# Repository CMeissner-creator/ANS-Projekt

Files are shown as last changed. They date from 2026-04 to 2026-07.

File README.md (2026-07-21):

# ANS-Projekt

Das ANS-Projekt hat zum Ziel einen 5,5 MHz Colpitts Oszilator zu entwerfen

- Kundenwünsche / Ursprüngliche Zielsetzung
- KiCad Projekte der Entwicklung
- Messwerte des Aufbau

Die Website wird automatisch aus dem Ordner `docs/` generiert.

# Kunden Anforderungen
- 5,5 MHz Mittenfrequenz (Zwischenfrequenz Fernseher)
- Eingang 0 V
- linear ± 0,5 V ≙ ± 0,5 MHz
- Bandbreite von 5 bis 6 MHz
- nicht lineare Verzerrung sehr klein
- Robuste Platine für anschaulichen Unterricht
- große Bauteile
- Spannungsteiler integriert
- Ein- und Ausgang BNC
- Ausgangswiderstand 50 Ω
- Frequenzdrift durch Gleichspannung korrigiert
- Kennlinienermittlung mit Gleichspannung
- Kurzschluss sicher

## Quellen für den Colpitts Oszillator
- [Elektroniktutor FM Modulation](https://www.elektroniktutor.de/signalkunde/fm.html)
- [Elektroniktutor Colpitts Oszillator](https://www.elektroniktutor.de/signalkunde/colpitts.html)

### Coilpitts Oszillator in Emitterschaltung für 125 kHz

Als erstes haben wir den Colpitts Oszillator für für 125 kHz von der Elektroniktutor
Seite in KiCad und danach auf einer Platine aufgebaut.

[Schaltplan als PDF](/docs/assets/Colpitts_Oszillator.pdf)

Danach haben wir versucht diesen Oszilator auf 5,5 Mhz umzubauen:

[Schaltplan als PDF](/docs/assets/Colpitts_Oszillator_5.5MHz.pdf)

In der NGSpice / KiCad Simulation funktioniert der Oszilator so, aber in der Realität nicht.
Das Problem ist, dass ein Colpitts Oszilator in der Emitterschaltung bei so hohen Frequenzen nicht funktioniert.
Die Millerkapazität, des Transistor, macht die Emitterschaltung unmöglich im MHz Bereich.

#### Colpitts Oszillator in Basisschaltung für 5,5 MHz

So sind wir schließlich bei einem Colpitts Oszillator in Basisschaltung gelandet.

[Schaltplan als PDF](/docs/assets/FM-ELK.pdf)

Dieser funktioniert so im Steckbrettaufbau.

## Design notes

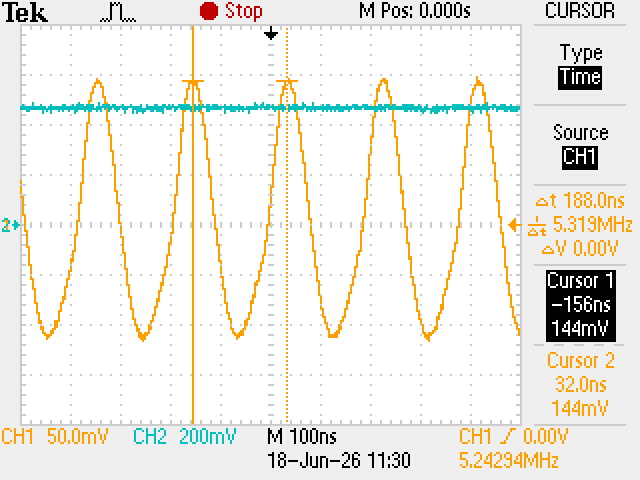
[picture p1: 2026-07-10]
Messungen/Oszillator_Bilder/TEK0002.JPG

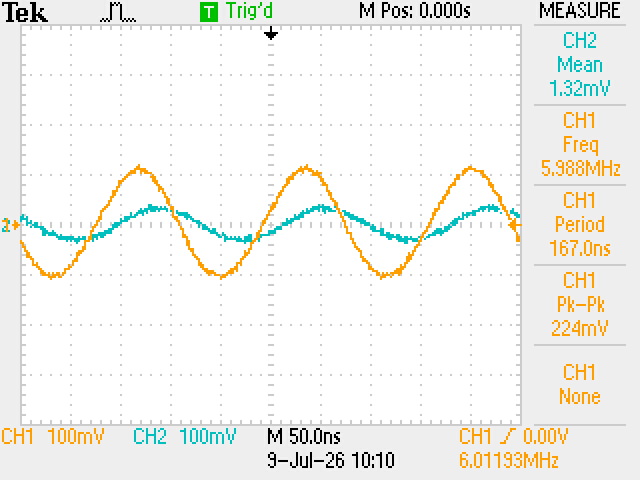
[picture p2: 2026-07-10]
Messungen/Messung 09.07.2026/TEK0008.JPG

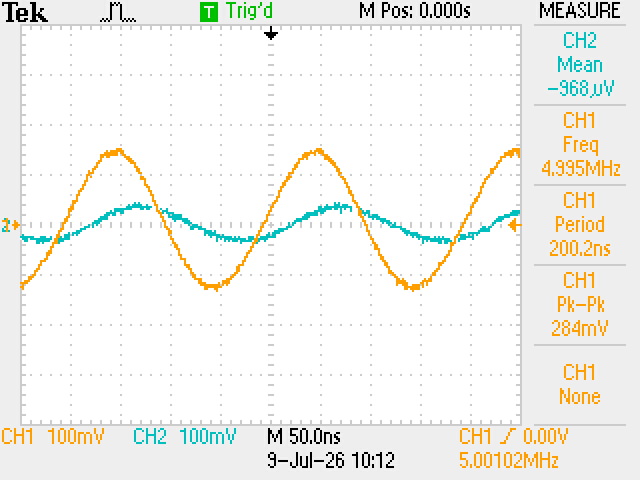
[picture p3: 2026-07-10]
Messungen/Messung 09.07.2026/TEK0010.JPG

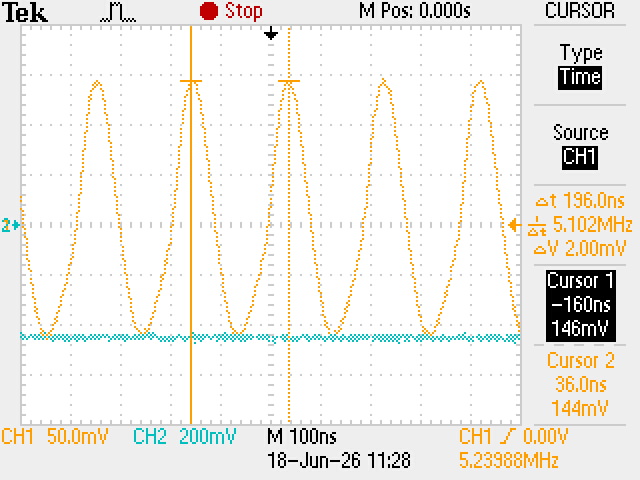
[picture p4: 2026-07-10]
Messungen/Oszillator_Bilder/TEK0001.JPG

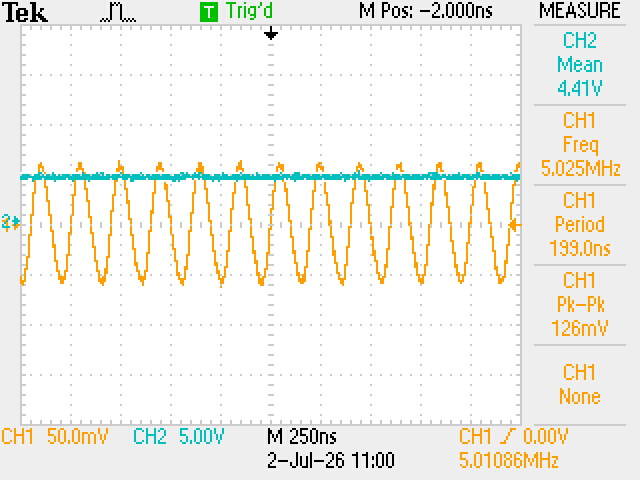
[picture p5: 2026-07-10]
Messungen/Oszillator_Bilder/TEK0007.JPG

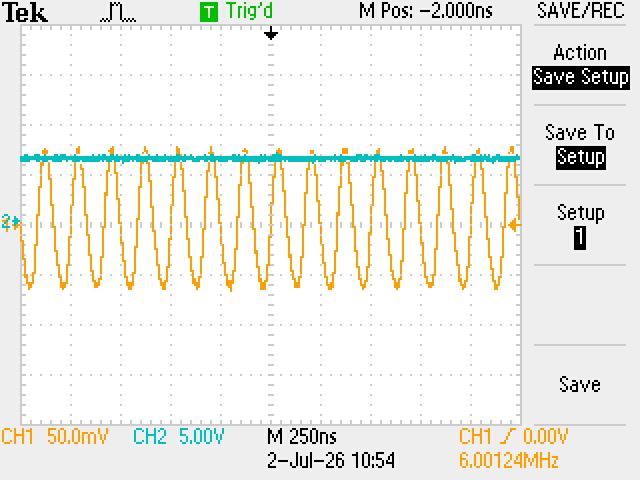
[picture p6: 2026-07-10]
Messungen/Oszillator_Bilder/TEK0004.JPG

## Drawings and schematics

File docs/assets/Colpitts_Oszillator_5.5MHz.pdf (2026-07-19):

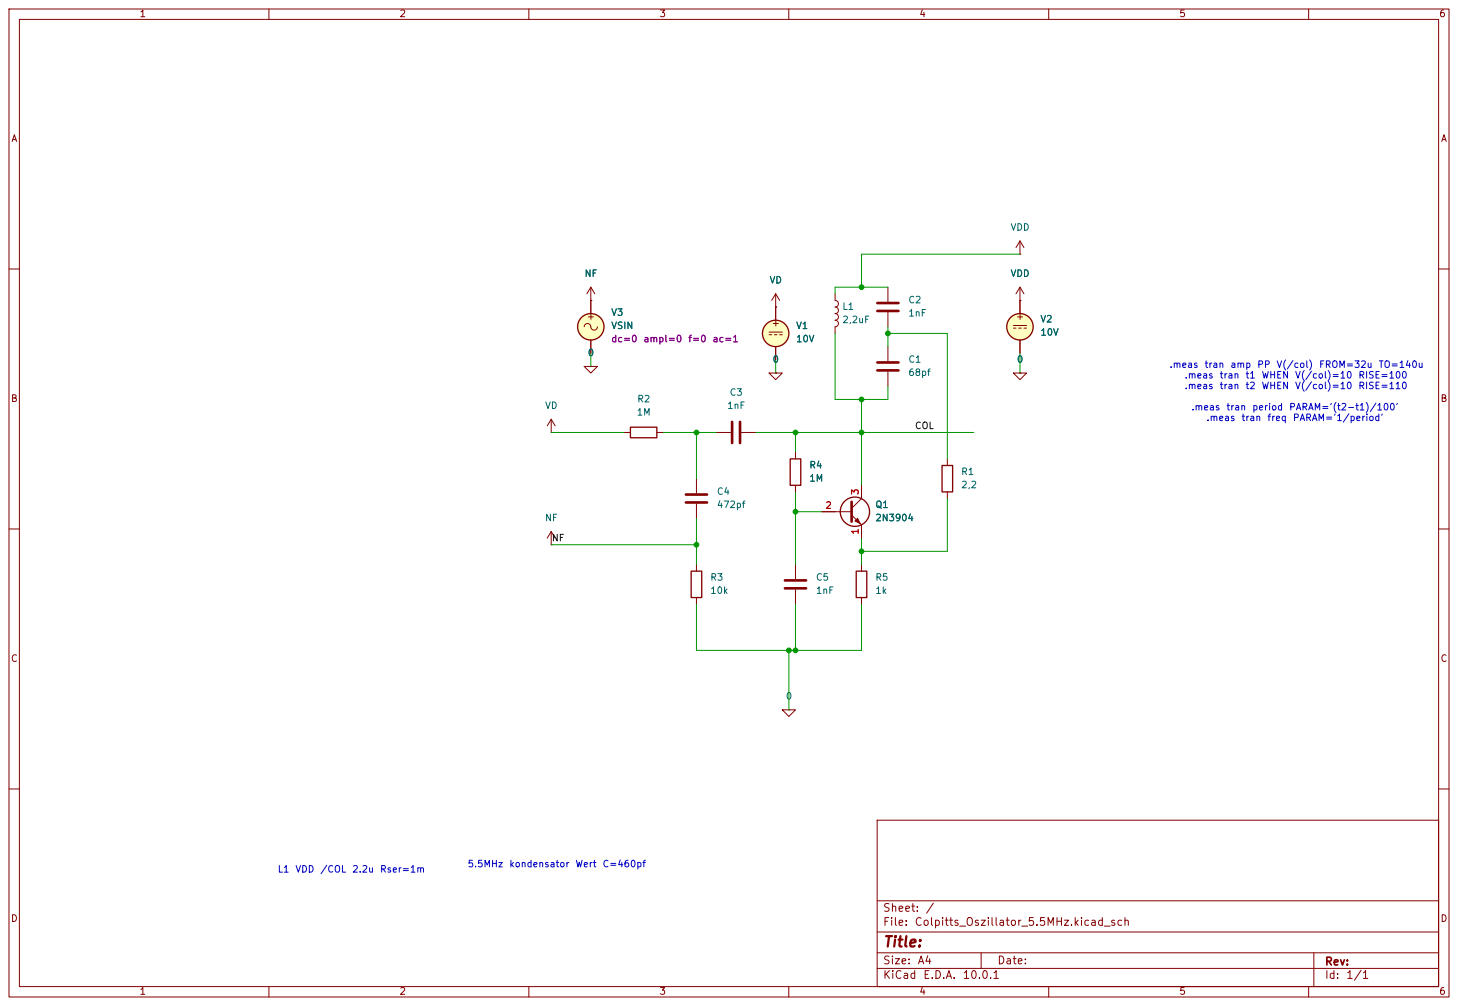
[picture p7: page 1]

.meas tran amp PP V(/col) FROM=32u TO=140u
.meas tran t1 WHEN V(/col)=10 RISE=100
.meas tran t2 WHEN V(/col)=10 RISE=110

.meas tran period PARAM='(t2-t1)/100'

.meas tran freq PARAM='1/period' 5.5MHz kondensator Wert C=460pf L1 VDD /COL 2.2u Rser=1m

Size: A4 | Rev:
KiCad E.D.A. 10.0.1 | Id: 1/1

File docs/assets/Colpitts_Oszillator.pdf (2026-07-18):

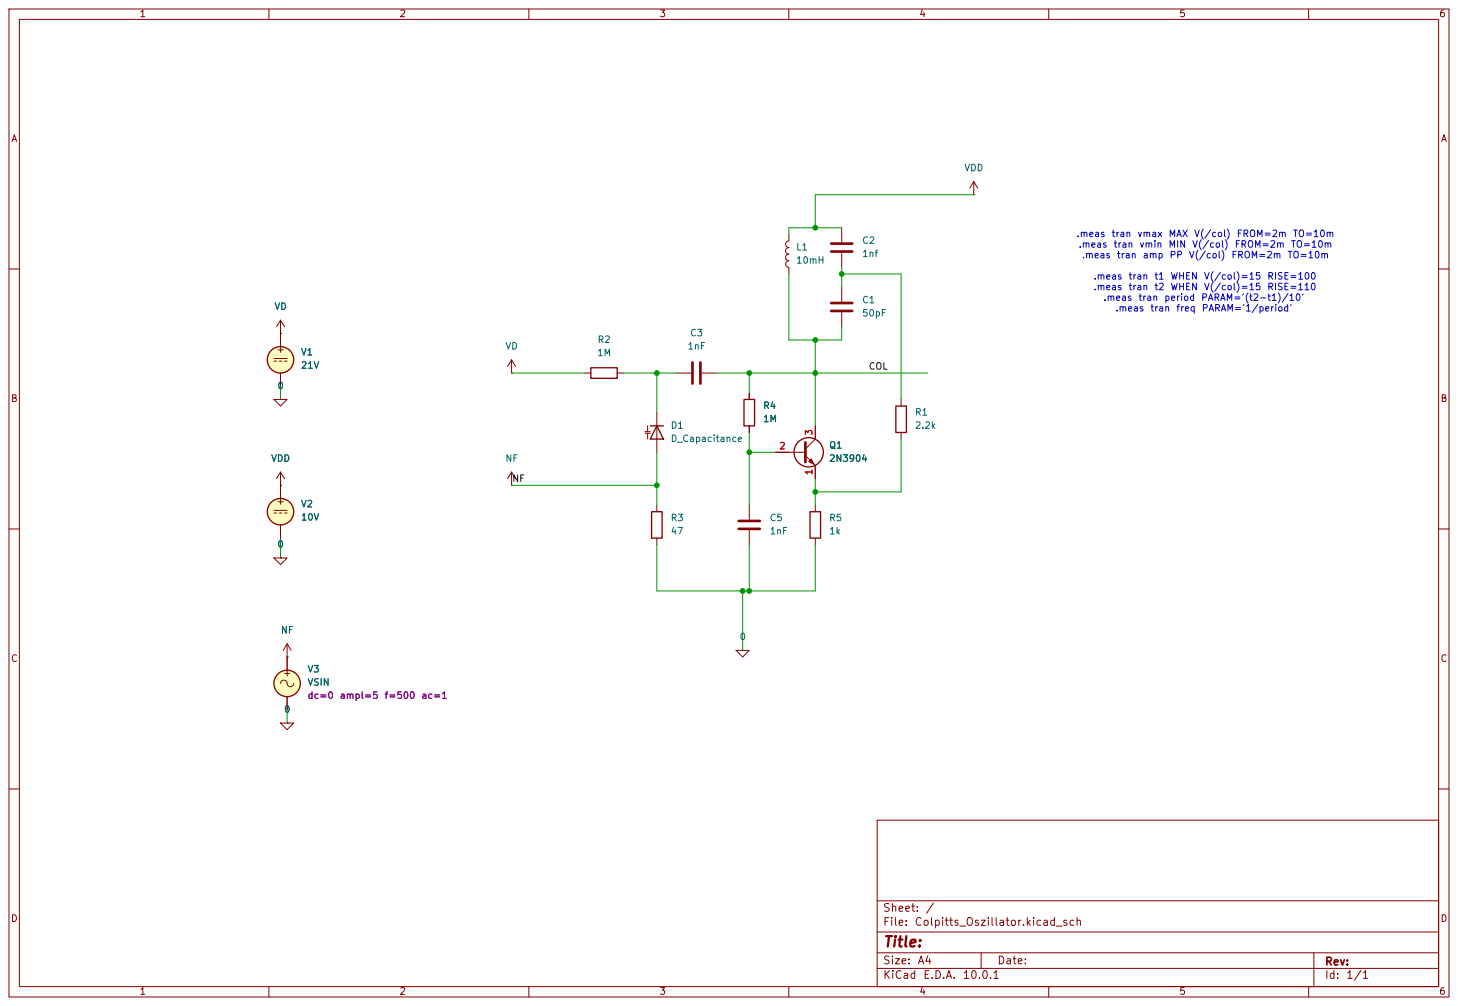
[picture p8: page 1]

.meas tran vmax MAX V(/col) FROM=2m TO=10m
.meas tran vmin MIN V(/col) FROM=2m TO=10m
.meas tran amp PP V(/col) FROM=2m TO=10m

.meas tran t1 WHEN V(/col)=15 RISE=100
.meas tran t2 WHEN V(/col)=15 RISE=110
.meas tran period PARAM='(t2-t1)/10'

.meas tran freq PARAM='1/period' Q1

Size: A4 | Rev:
KiCad E.D.A. 10.0.1 | Id: 1/1

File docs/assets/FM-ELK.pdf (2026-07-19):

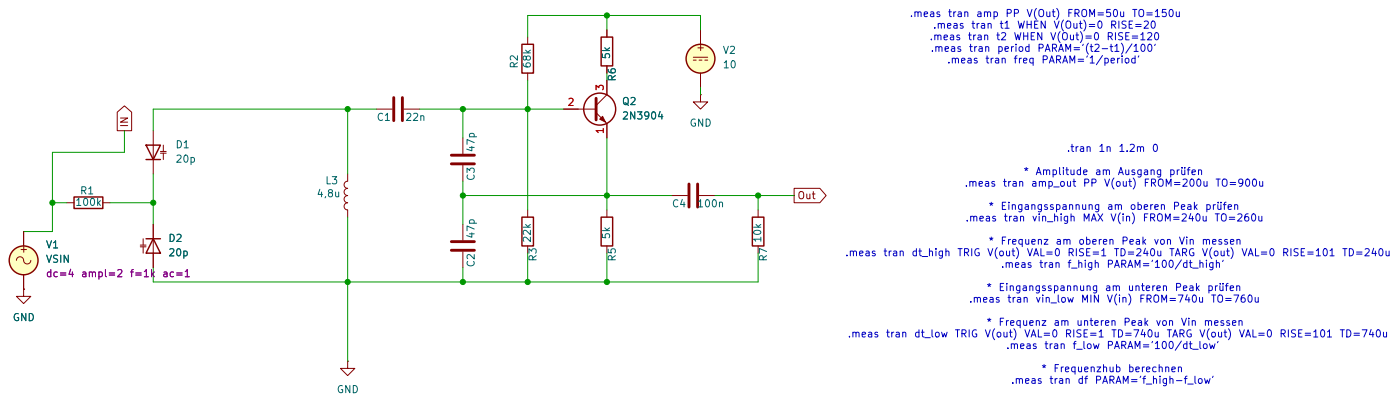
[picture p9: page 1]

.meas tran amp PP V(Out) FROM=50u TO=150u
.meas tran t1 WHEN V(Out)=0 RISE=20
.meas tran t2 WHEN V(Out)=0 RISE=120
.meas tran period PARAM='(t2-t1)/100'
.meas tran freq PARAM='1/period'

University of applied sience R268k

* Amplitude am Ausgang prüfen

.meas tran amp_out PP V(out) FROM=200u TO=900u

* Eingangsspannung am oberen Peak prüfen
.meas tran vin_high MAX V(in) FROM=240u TO=260u

* Frequenz am oberen Peak von Vin messen

.meas tran dt_high TRIG V(out) VAL=0 RISE=1 TD=240u TARG V(out) VAL=0 RISE=101 TD=240u

.meas tran f_high PARAM='100/dt_high' * Eingangsspannung am unteren Peak prüfen

.meas tran vin_low MIN V(in) FROM=740u TO=760u

* Frequenz am unteren Peak von Vin messen

.meas tran dt_low TRIG V(out) VAL=0 RISE=1 TD=740u TARG V(out) VAL=0 RISE=101 TD=740u

.meas tran f_low PARAM='100/dt_low' * Frequenzhub berechnen

Title: Name of circuit / Creator

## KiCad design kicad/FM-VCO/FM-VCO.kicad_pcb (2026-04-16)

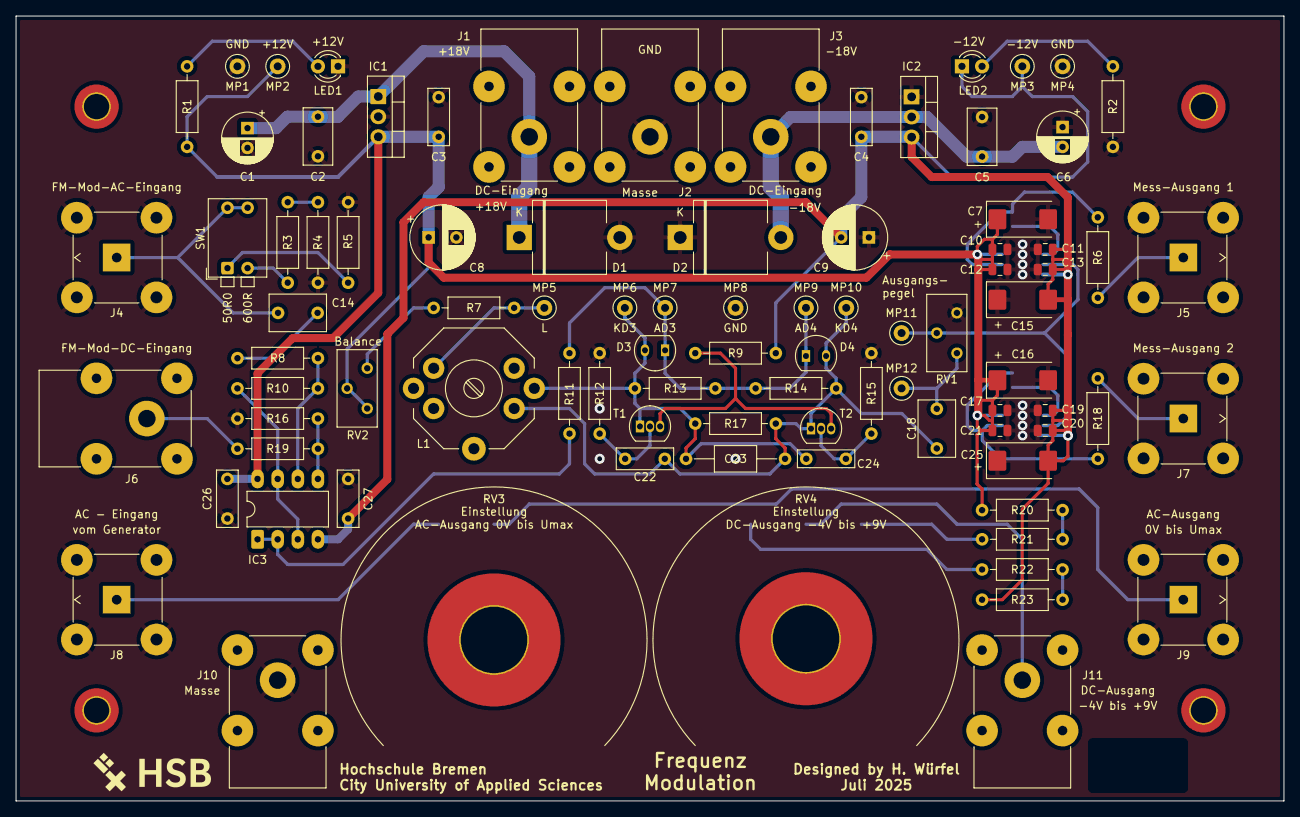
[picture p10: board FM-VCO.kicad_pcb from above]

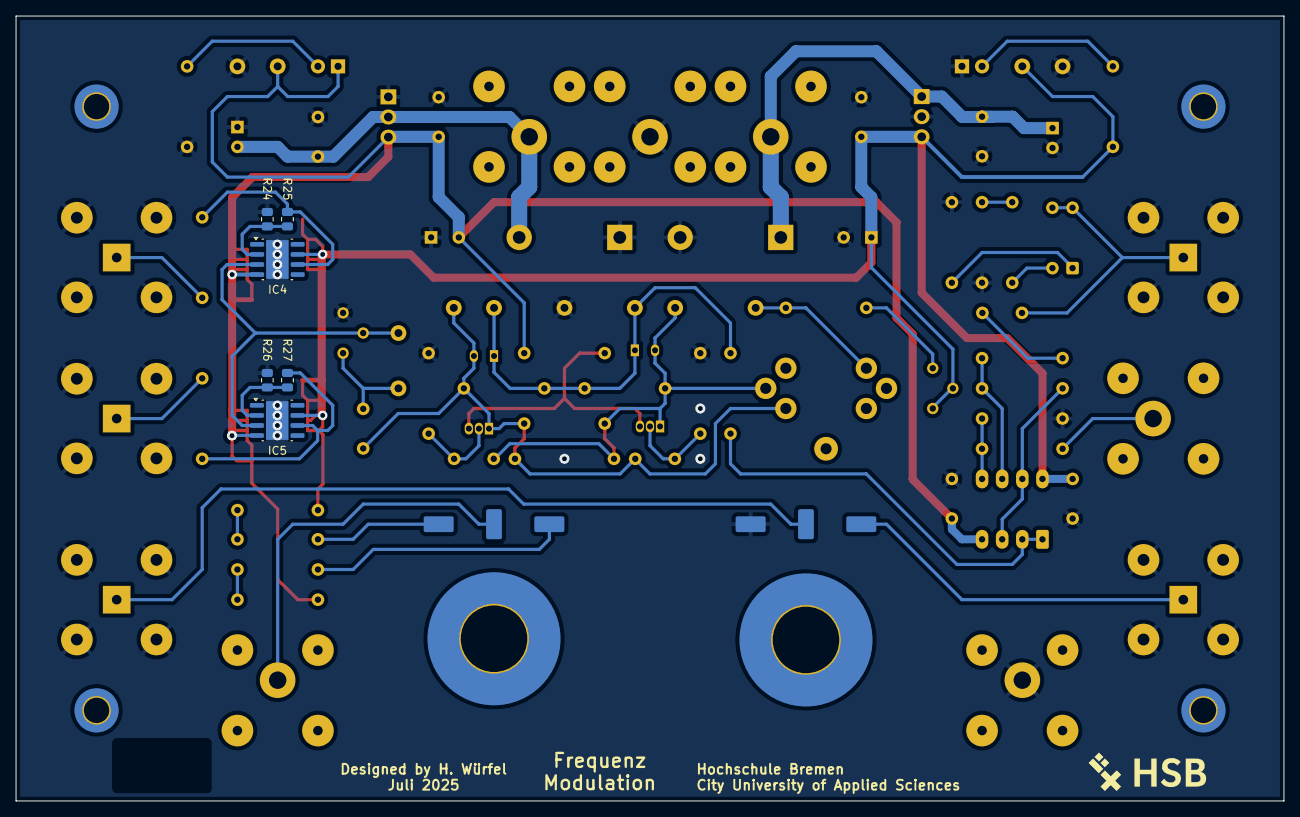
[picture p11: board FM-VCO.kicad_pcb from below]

Board: 2 copper layers, 160.0 x 99.1 mm, 104 parts (7 on the bottom side), 40 nets.

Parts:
C1, C6: 10µ; CP_Radial_D6.3mm_P2.50mm
C2, C5: 330n; C_Rect_L7.0mm_W3.5mm_P5.00mm
C3, C4, C26, C27: 100n; C_Rect_L7.0mm_W2.5mm_P5.00mm
C7, C15, C16, C25: 10µ; CP_EIA-7343-31_Kemet-D_Pad2.25x2.55mm_HandSolder
C8, C9: 100µ; CP_Radial_D8.0mm_P3.50mm
C10, C13, C17, C20: 1n; C_0805_2012Metric
C11, C12, C19, C21: 47n; C_0805_2012Metric
C14, C18: 1µ0; C_Rect_L7.0mm_W4.5mm_P5.00mm
C22: 22n; C_Rect_L7.0mm_W2.5mm_P5.00mm
C23: 68p; C_Axial_L5.1mm_D3.1mm_P12.50mm_Horizontal
C24: 22n; C_Rect_L7.0mm_W2.0mm_P5.00mm
D1, D2: P600G; D_P600_R-6_P12.70mm_Horizontal
D3, D4: BB112
G*: LOGO; HSB-Logo
G*#2: LOGO; HSB-Logo
H1, H2, H5, H6: MountingHole; MountingHole_3.2mm_M3_DIN965_Pad_TopBottom
H3, H4: MountingHole; MountingHole_8.4mm_M8_Pad_TopBottom
IC1: LM7812_TO220; TO-220-3_Vertical
IC2: LM7912_TO220; TO-220-3_Vertical
IC3: TL082; DIP-8_W7.62mm_LongPads
IC4, IC5: THS3091DDAR; Texas_R-PDSO-G8_EP2.95x4.9mm_Mask2.4x3.1mm
J1: +18V; Banana_Cliff_FCR7350B_S16N-PC_Horizontal_modi
J2, J10: GND; Banana_Cliff_FCR7350B_S16N-PC_Horizontal_modi
J3: -18V; Banana_Cliff_FCR7350B_S16N-PC_Horizontal_modi
J4: FM-Mod-AC-Eingang; BNC_TEConnectivity_1478035_Horizontal
J5: Mess-Ausgang 1; BNC_TEConnectivity_1478035_Horizontal
J6: FM-Mod-DC-Eingang; Banana_Cliff_FCR7350B_S16N-PC_Horizontal_modi
J7: Mess-Ausgang 2; BNC_TEConnectivity_1478035_Horizontal
J8: AC - Eingang; BNC_TEConnectivity_1478035_Horizontal
J9: AC-Ausgang; BNC_TEConnectivity_1478035_Horizontal
J11: DC-Ausgang; Banana_Cliff_FCR7350B_S16N-PC_Horizontal_modi
L1: 7µ 7µ; Spule_Vielstedter_14mm
LED1, LED2: gn; LED_D3.0mm_Clear
MP1, MP4, MP8: GND; TestPoint_Loop_D2.50mm_Drill1.0mm
MP2: +12V; TestPoint_Loop_D2.50mm_Drill1.0mm
MP3: -12V; TestPoint_Loop_D2.50mm_Drill1.0mm
MP5: L; TestPoint_Loop_D2.50mm_Drill1.0mm
MP6: KD3; TestPoint_Loop_D2.50mm_Drill1.0mm
MP7: AD3; TestPoint_Loop_D2.50mm_Drill1.0mm
MP9: AD4; TestPoint_Loop_D2.50mm_Drill1.0mm
MP10: KD4; TestPoint_Loop_D2.50mm_Drill1.0mm
MP11: U-Treiber-In; TestPoint_Loop_D2.50mm_Drill1.0mm
MP12: Pegel; TestPoint_Loop_D2.50mm_Drill1.0mm
R1, R2: 470R; R_Axial_DIN0207_L6.3mm_D2.5mm_P10.16mm_Horizontal
R3: 590R; R_Axial_DIN0207_L6.3mm_D2.5mm_P10.16mm_Horizontal
R4: 10R0; R_Axial_DIN0207_L6.3mm_D2.5mm_P10.16mm_Horizontal
R5, R6, R18: 50R0; R_Axial_DIN0207_L6.3mm_D2.5mm_P10.16mm_Horizontal
R7: 3K3; R_Axial_DIN0207_L6.3mm_D2.5mm_P10.16mm_Horizontal
R8, R9, R10, R12, R15, R16, R19: 10K0; R_Axial_DIN0207_L6.3mm_D2.5mm_P10.16mm_Horizontal
R11: 4K7; R_Axial_DIN0207_L6.3mm_D2.5mm_P10.16mm_Horizontal
R13, R14: 22K0; R_Axial_DIN0207_L6.3mm_D2.5mm_P10.16mm_Horizontal
R17: 1M0; R_Axial_DIN0207_L6.3mm_D2.5mm_P10.16mm_Horizontal
R20: 1K1; R_Axial_DIN0207_L6.3mm_D2.5mm_P10.16mm_Horizontal
R21: 39R0; R_Axial_DIN0207_L6.3mm_D2.5mm_P10.16mm_Horizontal
R22: 300R; R_Axial_DIN0207_L6.3mm_D2.5mm_P10.16mm_Horizontal
R23: 2K7; R_Axial_DIN0207_L6.3mm_D2.5mm_P10.16mm_Horizontal
R24, R25, R26, R27: 1K2; R_0805_2012Metric
RV1: 20K0; Potentiometer_Bourns_3296Y_Vertical
RV2: 1K0; Potentiometer_Bourns_3296Y_Vertical
RV3: 5K0; Taiss_10Gang_Poti
RV4: 5k0; Taiss_10Gang_Poti
SW1: SW_DIP_x02; SW_DIP_SPSTx02_Piano_CTS_Series194-2MSTN_W7.62mm_P2.54mm
T1, T2: BC546B; TO-92_Inline

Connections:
+12V: C3.1, C7.1, C8.1, C10.1, C12.1, C16.1, C17.2, C21.2, C26.1, IC1.3 (VO), IC3.8 (V+), IC4.7 (V+), IC5.7 (V+), MP2.1, R1.1, R20.2, RV2.1, RV2.2
-12V: C4.2, C9.2, C11.2, C13.2, C15.2, C19.2, C20.2, C25.2, C27.1, IC2.3 (VO), IC3.4 (V-), IC4.4 (V-), IC5.4 (V-), LED2.1 (K), MP3.1, R9.1, R23.2
/FM-Spannungsversorgung/+18V: C1.1, C2.1, D1.1 (K), IC1.1 (VI), J1.1
/FM-Spannungsversorgung/-18V: C5.2, C6.2, D2.2 (A), IC2.2 (VI), J3.1
/IN: IC4.3 (+), IC5.3 (+), MP11.1, RV1.2
/OUT-1: J5.1 (In), R6.2
/OUT-2: J7.1 (In), R18.2
GND: C1.2, C2.2, C3.2, C4.1, C5.1, C6.1, C7.2, C8.2, C9.1, C10.2, C11.1, C12.2, C13.1, C15.1, C16.2, C17.1, C19.1, C20.1, C21.1, C25.1, C26.2, C27.2, D1.2 (A), D2.1 (K), IC1.2 (GND), IC2.1 (GND), IC4.9 (EP), IC5.9 (EP), J2.1, J4.2 (Ext), J5.2 (Ext), J7.2 (Ext), J8.2 (Ext), J9.2 (Ext), J10.1, LED1.1 (K), MP1.1, MP4.1, MP8.1, R2.1, R4.2, R5.2, R12.1, R15.1, R16.2, R24.1, R26.1, RV1.3, RV3.3
unnamed: C14.2, R8.1
unnamed: D3.2 (A), D4.2 (A), MP7.1, MP9.1, R11.1, R13.1, R14.2
unnamed: C23.1, C24.1, D3.1 (K), L1.2, MP6.1, R13.2, R17.1, T1.1 (C)
unnamed: C18.1, C22.2, C23.2, D4.1 (K), L1.3, MP10.1, R14.1, R17.2, T2.1 (C)
unnamed: IC3.3 (+), IC3.7, R10.2
unnamed: IC3.1, IC3.2 (-), R11.2
unnamed: IC3.5 (+), R16.1, R19.2
unnamed: IC3.6 (-), R8.2, R10.1
unnamed: IC4.2 (-), R24.2, R25.1
unnamed: IC4.6, R6.1, R25.2
unnamed: IC5.2 (-), R26.2, R27.1
unnamed: IC5.6, R18.1, R27.2
unnamed: C14.1, J4.1 (In), SW1.3, SW1.4
unnamed: J6.1, R19.1
unnamed: J8.1 (In), RV3.1
unnamed: J9.1 (In), RV3.2
unnamed: J11.1, RV4.2
unnamed: LED1.2 (A), R1.2
unnamed: LED2.2 (A), R2.2
unnamed: L1.6, MP5.1, R7.2
unnamed: C18.2, MP12.1, RV1.1
unnamed: R3.1, SW1.2
unnamed: R3.2, R4.1
unnamed: R5.1, SW1.1
unnamed: R7.1, RV2.3
unnamed: R20.1, R21.2
unnamed: R21.1, RV4.1
unnamed: R22.1, RV4.3
unnamed: R22.2, R23.1
unnamed: C22.1, R12.2, T1.2 (B)
unnamed: R9.2, T1.3 (E), T2.3 (E)
unnamed: C24.2, R15.2, T2.2 (B)

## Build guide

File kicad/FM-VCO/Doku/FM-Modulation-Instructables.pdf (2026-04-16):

## FM Modulation/de-modulation Circuit

By brmarcum (https://www.instructables.com/member/brmarcum/) in Circuits (https://www.instructables.com/circuits/)Electronics (https://www.instructables.com/circuits/electronics/projects/)

## Introduction: FM Modulation/de-modulation Circuit

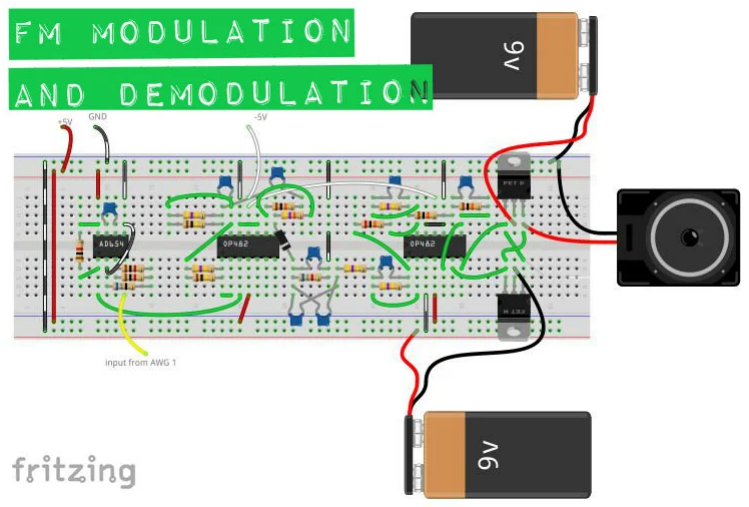
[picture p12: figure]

I got the idea for this circuit from one of my professors. That design wasn't meant for passing frequencies high enough to be able to pass an audio file, e.g. 500Hz+, so I built this by modifying the carrier and signal frequencies, using only the Digilent Analog Discovery (http://digilentinc.com/Products/Detail.cfm?NavPath=2,1040,1043&Prod=ANALOG-DISCOVERY) and the Analog Parts Kit. (http://digilentinc.com/Products/Detail.cfm?NavPath=2,1040,1066&Prod=APK) It should be noted that this circuit is primarily for educational purposes. Also note that there is no radio transmission here either. FM doesn't necessarily mean radio waves have to be involved.

Throughout this Instructable I will be going through some of the functions and features of the Analog Discovery, but it will not be an exhaustive tutorial.

## Step 1: Parts and Tools

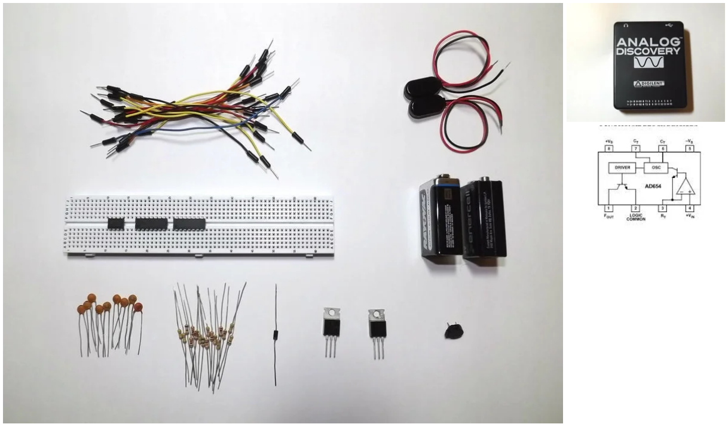
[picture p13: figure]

All of the parts listed below are provided in the Analog Starter Kit, (http://digilentinc.com/Products/Detail.cfm?NavPath=2,1040,1066&Prod=APK) except for the 9V batteries and clips. They should also be available through various online suppliers, local shops, or the salvage bin on your workbench.

The Parts:

- 2 OP482 quad op-amps (datasheet) (http://www.analog.com/static/imported-files/data_sheets/OP282_482.pdf)
- AD654 voltage to frequency converter (datasheet) (http://www.analog.com/static/imported-files/data_sheets/AD654.pdf)
- 9 ceramic capacitors: 2 - 39pF (39), 2 - 100pF (101), 2 - 1nF (102), 2 - 4.7nF (472), 1 - 10nF (103)
- 17 carbon film resistors: 1 - 68, 3 - 1k, 1 - 6.8k, 3 - 10k, 1 - 20k, 1 - 47k, 2 - 100k, 5 - 470k
- 1 1N4001 rectifier diode
- 1 speaker
- solderless breadboard
- jumper wires

(optional)

- 1 TIP31C NPN BJT
- 1 TIP32C PNP BJT
- 2 9V batteries with clips

The Tools:

- Digilent Analog Discovery (http://digilentinc.com/Products/Detail.cfm?NavPath=2,1040,1043&Prod=ANALOG-DISCOVERY)
- Waveforms (http://digilentinc.com/Products/Detail.cfm?NavPath=2,66,849&Prod=WAVEFORMS) software (free but required to run the Analog Discovery)
- short, free .wav (http://www.wavsource.com/) file download.

Pin-out diagrams are included for the OP482 quad op-amp and AD654 voltage to frequency converter, also called a voltage controlled oscillator or VCO.

## Step 2: Designing

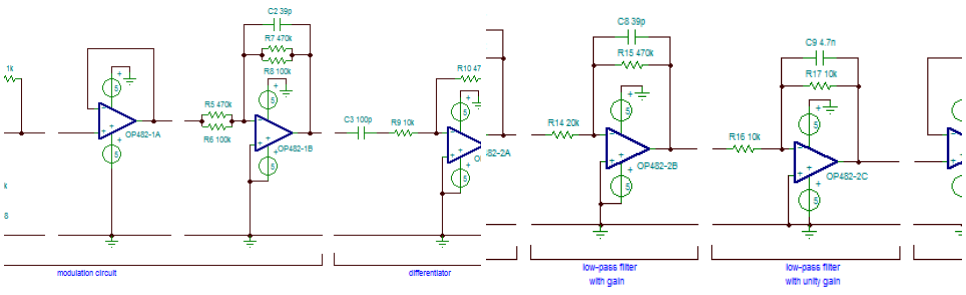
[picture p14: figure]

The schematic for this can be daunting to say the least. When I first started working with it, I got lost all the time and had to keep going back over it again and again. You'll notice in the schematic that there are breaks throughout the design. Each of those breaks represents a good stopping point for verifying the circuit function. Take it slow and add one section at a time. The OP482 ICs are quad op-amps, meaning four op-amps on one piece of silicone. That can make it tricky to hook everything together as components can get crowded. This project can be built using individual op-amps if that is easier for you, but I would recommend using the OP27 and not the LM741. The LM741 should work, but I have had problems with it when it comes to needing fast, reliable response times. The specs are just a bit too slow for some applications, specifically the skew rate when you need high gain at a relatively high frequency.

For clarification the schematic image is broken up. Point A matches to point A, B with B.

## Step 3: Frequency Modulation

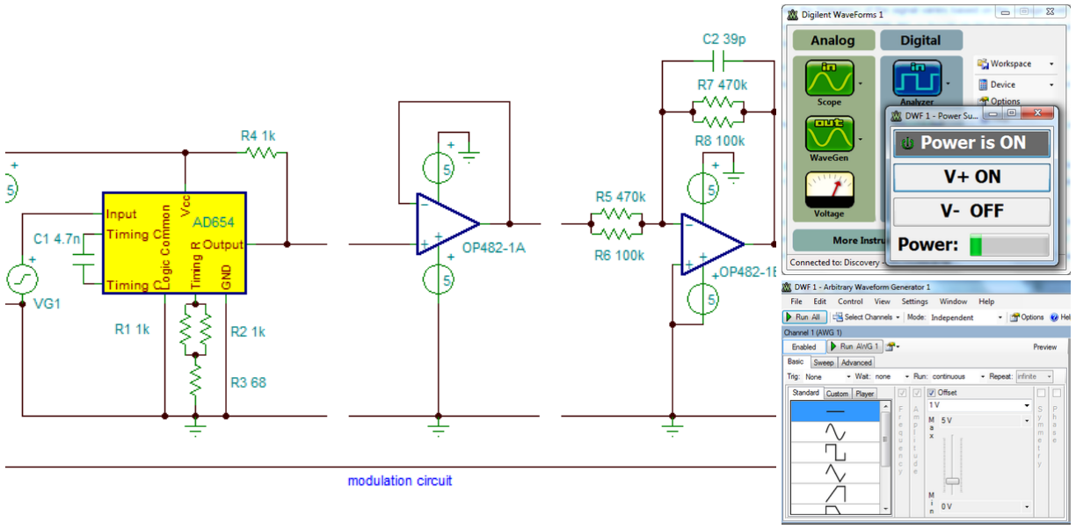
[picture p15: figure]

I won't go into the details of FM or AM technology too much here. I would refer you to Wikipedia (http://en.wikipedia.org/wiki/Frequency_modulation) for that (note the animation on the right side of the page). In a nutshell, for FM signals, the frequency of the signal varies based on the voltage level coming in. So a high voltage gives a high frequency, and vice versa. With AM, the frequency stays the same, but the amplitude goes high or low depending on the input voltage. As you will see, this circuit actually uses both.

The higher frequency signal is the carrier frequency, while the original signal is the data that you want to relay. We will use the data signal to modulate a much higher frequency carrier wave. Later we will filter out the carrier and recover the data.

The first three sections of the schematic are the modulation circuit. We first modulate the carrier wave, then amplify it. The AD654 changes the frequency of the output based on the voltage level of the input. The timing resistors and capacitors give a base frequency value for the IC to work with based on the equation found in the datasheet.

Using pages 1 and 4 of the datasheet (http://www.analog.com/static/imported-files/data_sheets/AD654.pdf) for the AD654, connect the components as shown. Note that 'Vs' indicates voltage supply, so '+Vs' is +5V and '-Vs' is ground. '+Vin' is the signal coming from the Analog Discovery AWG Channel 1 pin, labeled 'input' in the schematic.

Turn on the Voltage function from the Waveforms main window (image 2). Click V+ to 'ON', connect the red V+ wire from the Discovery header to pin 8 on the AD654, then turn it on. Using the Discovery's AWG channel 1, output a 1VDC signal (image 3) and plug it into pin 4 of the AD654. You should get a readout on the scope like image 4.

Next we add the first OP482. The first part is a simple voltage follower or buffer. (http://en.wikipedia.org/wiki/Voltage_follower) Since op-amps are active components, we will get a boost in current from this part. Next we add an active low-pass filter (http://en.wikipedia.org/wiki/Low-pass_filter) set to cutoff at approximately 50kHz, which is high enough to allow our signal to pass through but low enough to filter out random high frequency noise we don't want. When connecting the OP482, connect the Discovery's red V+ wire to pin 4 and the white V- wire to pin
11. Turn on the power supply (like in image 2, but both channels this time) before turning on AWG 1 with the signal. Set AWG 1 to an amplitude of 500mV this time. Your scope should look something image 5.

## Step 4: Differentiator and Envelope Detector

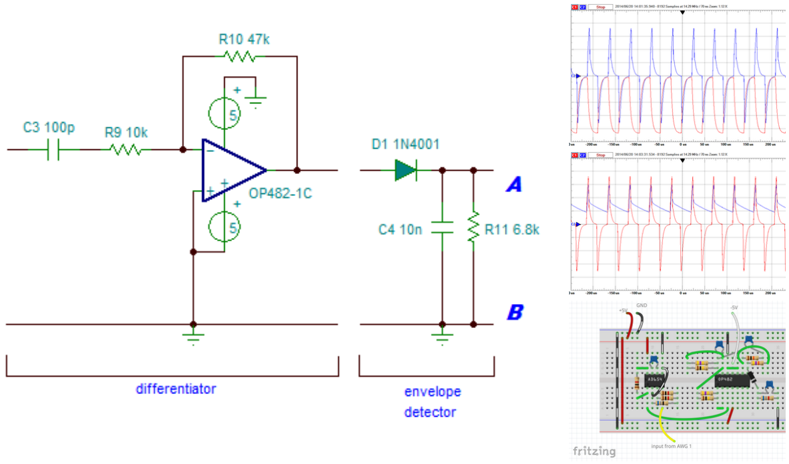
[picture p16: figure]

The theory behind most of these parts is a bit much to get into here. Again, check out wikipedia for the differentiator (http://en.wikipedia.org/wiki/Differentiator) (note that this one is active because of the op-amp) and the envelope detector explanations. In short, the differentiator, believe it or not, differentiates the signal (http://en.wikipedia.org/wiki/Envelope_detector) (think calculus and it makes total sense). As the input signal rises or falls quickly (high frequency), the output amplitude increases. As the input rises or falls slowly (low frequency), the output amplitude decreases closer to 0. This has the interesting effect of turning the FM signal into an AM signal. See the o-scope display in image 2 for a comparison (scope CH 1 to pin 14 of the OP482 and CH 2 to pin 8).

The envelope detector detects only the top edge of the signal, so as the amplitude rises and falls, so will the signal coming out of the envelope detector. See image 3 for an example (CH 1 to pin 8 of OP482 and CH 2 to cathode of 1N4001 diode).

## Step 5: Filtering

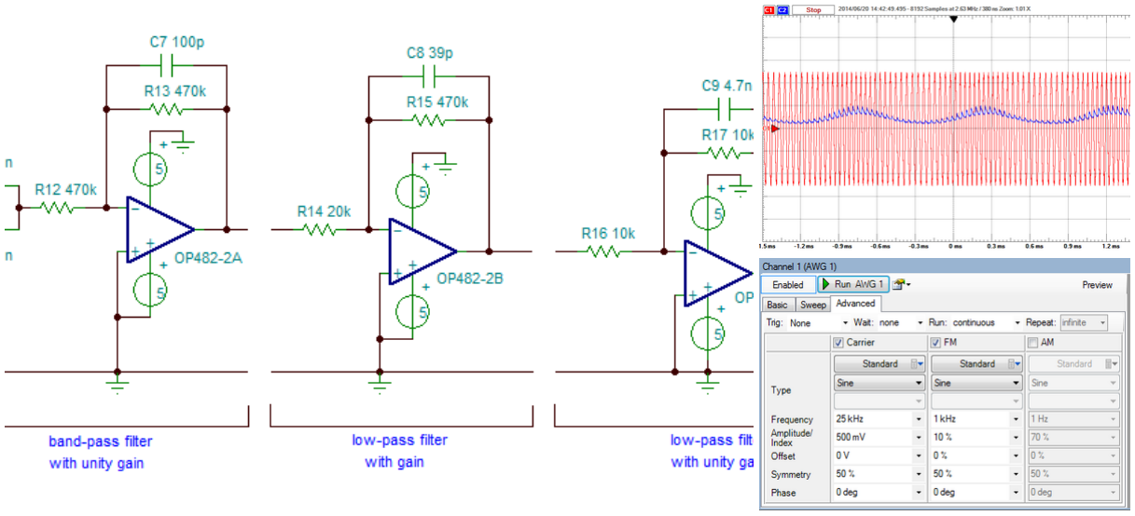
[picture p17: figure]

The signal from the envelope detector doesn't have much amplitude and contains quite a bit of noise. So we add several filters to both clarify and boost the signal. Look at the o-scope display in image 2. The red CH 1 signal is a 25kHz carrier with a 1kHz modulation frequency, amplitude of 500mV and index of 10%. These settings are all under the advanced tab on the Analog Discovery AWG tool (see image 3) if you would like to generate the signal yourself. This signal then is inserted into the input of the differentiator, bypassing the modulation circuit for now. The blue CH 2 is the output of the envelope detector, before any filtering. Do you see the scale on the left of the display in image 2? Each division is 20mV for CH 2. Most scopes will let you choose different scales for each channel, and here the scale for CH 1 is 200mV/div, larger by a factor of 10. With these two signals on a scale of 200mV/div, you would barely be able to see the output of the envelope detector because it is so weak. You can also see the noise in the signal as well in image 2. We need to filter that out and amplify the signal by a fair amount. We will also be running the signal through a band-pass filter to only allow audible frequencies between 200Hz and 2kHz to pass.

The first part is the band-pass filter. (http://en.wikipedia.org/wiki/Band-pass_filter) It allows only a small range of frequencies to pass through, and in our case 200Hz to 2kHz is more than enough. Note that because the resistors match, there is no gain here, only filtering. We don't want to amplify noise, so let's filter it out first.

After the band-pass filter we have two low-pass filters, (http://en.wikipedia.org/wiki/Low-pass_filter) the first with gain of approximately 23.5 and cutoff of about 8.6kHz, and the second with unity gain of 1, which means no amplification, and cutoff of about 3.4kHz. Even after the band-pass filter we still have some noise from the carrier wave (filters aren't perfect after all) and the signal is weak. We filter out noise above 8.6kHz and then amplify it 23.5 times. Yep, it's high but it needs it (you can change it by changing the resistor ratio. Click the low-pass filter link above for the equation). The second low-pass filter then further cleans up that signal by filtering noise above 3.4kHz, which is higher than our target range of 200Hz-2kHz, so we're good. The second filter is not absolutely necessary, but it did make a difference in the end.

Image 4 shows the difference in the signal between the output of the envelope detector and the output of the last filter. The scale is not exactly the same as before, but the data was just outside of range so I shrunk it down a little bit. Did you notice the measurement window at the bottom right? That's the 1kHz modulation value we saw in the settings in image 3 above. It's not a perfect sine wave, but it's a far sight cleaner than it was before, and it's good enough that you won't notice the difference.

If you don't want to add the class B amplifier, you're done here. Otherwise, get yourself some 9V batteries and turn the page.

## Step 6: Amplifying the Signal

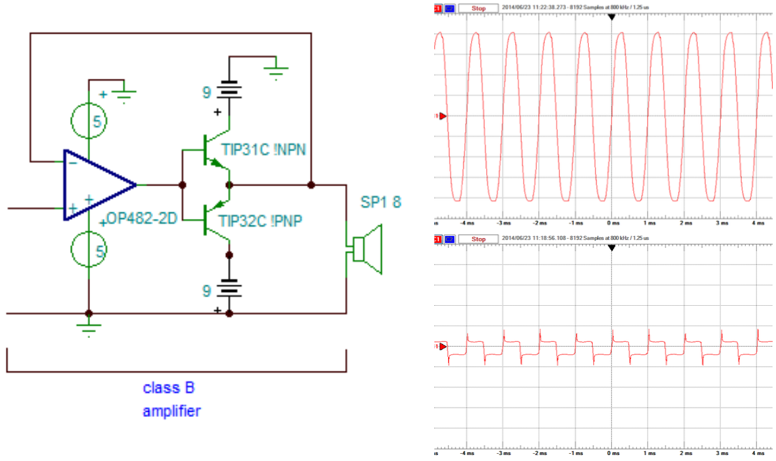
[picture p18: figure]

The 9 V batteries and connectors are not included with the Analog Parts Kit, and it is not absolutely necessary to amplify the signal coming from the last low-pass filter. However, as you can see from comparing images 2 and 3, the signal will clip when you add the speaker and form more of a square wave than a sine wave. A small 8-Ohm speaker will clip even more. This happens because the speaker itself also has a transfer function that must be accounted for, which is a fancy way of saying that it is trying to draw too much current at peak voltage, so it clips the voltage. It will actually sound louder, but won't be as clear. Adding the amplifier allows more current to be available and that allows the voltage level at the speaker match the output level at the last filter. Image 4 shows the signal with the amplifier in place and the speaker attached. The difference is minimal this time. I've used this on a 4-inch computer speaker I salvaged and even a 6-inch woofer and they all worked with this amplifier. Just remember that larger speakers require more current so you will drain your batteries faster.

When putting the BJTs on the breadboard it is very easy to get the pins mixed up. I've built this circuit, start to finish, at least half a dozen times, and I still did it. Again. I've included the pin-out diagram for them (they have the same B/C/E pin assignments), so good luck.

## Step 7: Testing

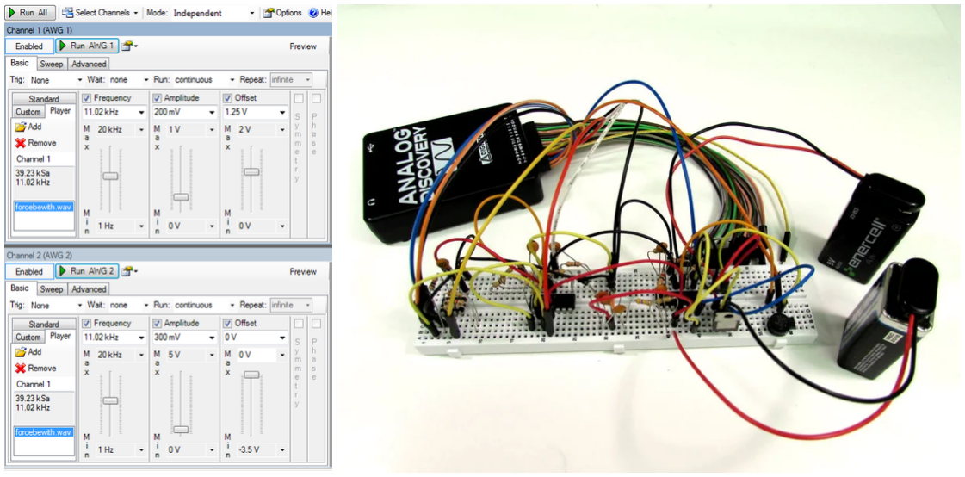
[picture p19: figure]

Now let's do some testing to verify. If you haven't yet downloaded a short .wav file, (http://www.wavsource.com/) do so now. Go into the AWG tool settings and check both channels to turn them both on. Click on the 'player' tab, then on 'add'. A window will come up to allow you to find the downloaded .wav file. Double click on it to load it. Notice the playback frequency in the window to the left? My file is set at 11.02kHz. For now, set the AWG channels to playback at this frequency. You won't break anything if you change it, it just changes the playback speed of the file. Load the file for both AWG channels. There are notes on the image that will help clarify this step.

Set the channels according to image 1, making sure that the offset for CH 1 is 1.25V. It will make a big difference and took me a while to troubleshoot the first time. The amplitude (volume) settings are not super critical, but remember that we are amplifying the signal by quite a lot in the circuit, so start smaller and work your way up as desired.

Start with CH 2 on the AWG and plug the yellow/white wire directly into the speaker, bypassing the entire circuit. This way you can hear the file playback on the speaker before passing it through the circuit. Once you have it playing on the speaker using CH 2, plug CH 1 into pin 4 of the AD654. Unplug AWG CH 2 from the speaker and connect the output of the class B amplifier to the speaker. You should hear the same playback either way.

And there you have it. Please don't hesitate to ask questions, either in the comments below or PM. Have fun building!

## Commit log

2026-04-16 Added report and kicad fm-vco
    [FM-Spannungsversorgung.kicad_sch, FM-Treiber.kicad_sch, FM-VCO.kicad_pcb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]
2026-07-10 Messungen hinzugefügt
    [FM-ELK.kicad_pcb, FM-ELK.kicad_sch]
2026-07-18 Remove KiCad .history repo from tracking
    [Colpitts_Oszillator_5.5MHz.kicad_pcb, Colpitts_Oszillator_5.5MHz.kicad_sch]
2026-07-19 Aktueller Stand
    [.kicad_sch, .kicad_sch.kicad_sch, Colpitts_Oszillator_5.5MHz.kicad_sch]
2026-07-19 Quarto Datei und HTML geandert
2026-07-19 Fix KiCad -history
